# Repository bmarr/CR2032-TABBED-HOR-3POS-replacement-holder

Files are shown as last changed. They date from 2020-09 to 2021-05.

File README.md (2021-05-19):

# CR2032-TABBED-HOR-3POS-replacement-holder

Created in 2020 Braden Marr

This work is licensed under a Creative Commons Attribution-NonCommercial-ShareAlike 4.0 International Public License
https://creativecommons.org/licenses/by-nc-sa/4.0/

This is a replacement battery holder originally intended for the 3V battery inside the 1985-1987 Korg DW-8000 synthesizer keyboard, though it will likely work as a replacement in other PCB designs that used the 3 pin welded coin battery. This battery holder allows for easier swaps of common CR2032 3V lithium coin batteries. It requires a small paperclip cut into two lengths to act as the pins and pressure contacts of the battery holder.

The battery keeps the sound patches in memory, but without this backup current, the RAM loses the sound patches and the keyboard is generally unusable by itself, except as a MIDI keyboard.

The original factory-installed battery lasted about 10 years if the keyboard was rarely used. The original battery was directly soldered into the main PCB and requires skilled de-soldering and soldering to remove and replace.

The unique battery holder shape avoids interference with nearby components on the board that would otherwise prevent off-the-shelf battery holders from being installed in the original battery location; because this design uses the existing holes for the battery terminals, it avoids the need for other electrical modifications to relocate existing components elsewhere.

Skilled de-soldering and re-soldering is still required for this battery holder, but if done correctly it should only have to be done this once! Use clippers to remove the original battery from the circuit board, then use solder cleanup techniques to remove the pins left behind and remove any excess solder. A copper wick desoldering technique works well, and a 0.7mm paperclip can be used as a sort of pipe-cleaner to prepare the through holes (3 of them) for the paperclip-pins that will be used as the battery contacts.

Note: A paperclip with a wire diameter of about 0.7mm to 0.8mm is used with this battery holder as the battery contacts. The three battery holes on the PCB accept pins with about 0.8mm diameter. The paperclip is cut into two lengths which are then bent to fit within the channels of the battery holder to make the + and - contacts with the battery and act as the pins through the PCB. The + length of paperclip also acts as a retainer for the coin battery.

!!! Solder the paperclips to the PCB without the holder in place, as the plastic will melt !!!

DO NOT USE THE gcode FILE IN THIS REPOSITORY FOR PRINTING! It is specific to a custom printer design and is provided here only for reference.

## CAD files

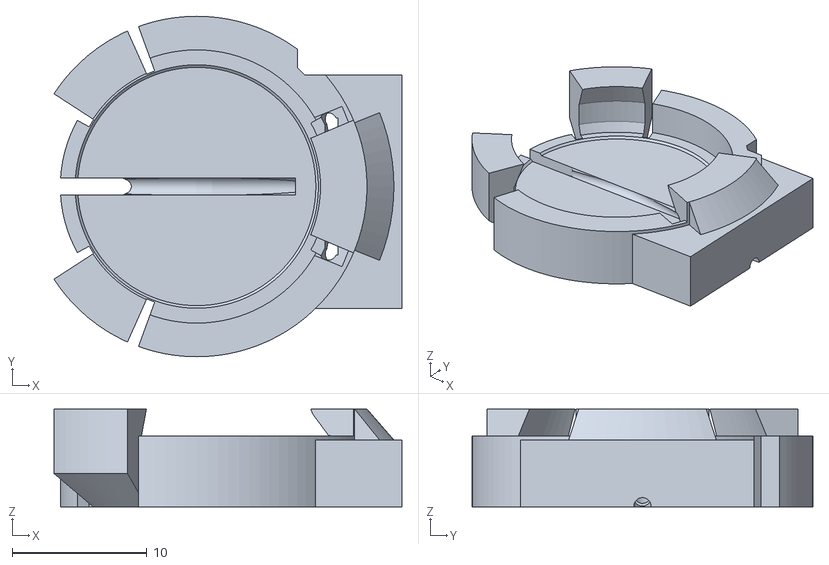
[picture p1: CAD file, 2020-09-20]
Korg-DW8000_CR2032-1GU_paperclip_battery_holder.stl
25.9 x 25.3 x 7.28

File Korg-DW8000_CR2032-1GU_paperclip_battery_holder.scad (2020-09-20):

// CR2032 battery socket for KORG DW8000
// Measurements based on datasheets for:
//  - Renesas CR2032-MFR-HR1/RH1 3-pin
//   industrial solder-in-place 225mAh Lithium battery,
//  - Panasonic CR2032-1GU 

$fn = 100;
d_coincell = 20; // 20 mm
d_coincell_tol = 0.3; // 0 to +0.3mm
d_coincell_neg = 17.7; // negative pad
h_coincell = 3.2; // 3.2 mm (2032)

d_min_hole_size = 0.7 + 0.25; // 0.7 from 1GU datasheet + IPC-2222 level A
d_min_annular_ring = 0.05; // 0.05mm
d_min_fab_allow = 0.6; // 0.6mm IPC-2222 level A
d_solder_pad = d_min_hole_size + d_min_annular_ring * 2 + d_min_fab_allow;
d_lead = 0.88; // 0.4 - 0.7mm for 1GU cell, paperclip = thicker? :)
d_hole_tol = 0.4; // FDM nozzle tolerance for small holes (for paperclips)

r_lead_pos_pin = 10.35;
y_lead_pos_pin1 = 10.15 / 2;
y_lead_pos_pin2 = -y_lead_pos_pin1;
y_lead_neg_pin = y_lead_pos_pin1 - 5.08;
x_lead_pos_pin1 = d_coincell / 2 + 0.35;
x_lead_pos_pin2 = x_lead_pos_pin1;
x_lead_neg_pin = x_lead_pos_pin1 - 16; // was 17.8, but then I measured the actual battery!
a_pos_pin = atan((y_lead_pos_pin1 - d_lead ) / (x_lead_pos_pin1 - d_lead / 2));
a_pos_pin_range = atan((y_lead_pos_pin1 + (d_lead / 2)) / (x_lead_pos_pin1 - d_lead / 2));
a_pos_pin_lean = -8;

h_holder_base = 1.2;
w_holder_walls = 2.5;
d_holder = d_coincell + d_coincell_tol + 2 * w_holder_walls;
a_holder_clip = 22; // angle of width of holder vertical flex tabs
h_holder_clip = 2; // height of clip overhang
w_holder_clip = 1; // extent of clip overhang
//w_holder_sweep = (sin(a_holder_clip) * ((d_coincell / 2) + d_coincell_tol + w_holder_walls)) / 2; // 
w_holder_sweep = w_holder_walls;
a_flex_relief_cut = 4; // 4 degrees for now, TODO: calculate

union() {
    difference() {
        union() {
            union() {
                difference() {
                    union() {
                        // battery enclosure
                        difference() {
                            translate([0, 0, 0])
                                cylinder(h = h_holder_base + d_lead + h_coincell, d1 = d_holder, d2 = d_holder);
                            translate([0, 0, h_holder_base + d_lead + 0.1])
                                coincell(h_coincell, d_coincell + d_coincell_tol, d_coincell_neg);
                        }
                        // upper retaining ring
                        translate([0, 0, h_holder_base + h_coincell + d_lead])
                            difference() {
                                difference() {
                                    translate([0, 0, 0])
                                        cylinder(h = h_holder_clip, d1 = d_holder, d2 = d_holder);
                                    translate([0, 0, -0.1])
                                        cylinder(h = h_holder_clip + 0.2, d1 = d_coincell + d_coincell_tol, d2 = d_coincell + d_coincell_tol - 2 * w_holder_clip);
                                }

                                // clip relief cuts
                                translate([0, 0, -0.01]) {
                                    // fingernail opening
                                    rotate(a = -180 - (a_holder_clip * 3) / 2, v = [0, 0, 1])
                                        rotate_extrude(angle = (a_holder_clip * 3), convexity = 10) {
                                                translate([d_coincell / 2 + (d_coincell_tol / 2) - w_holder_clip - 0.01, 0, 0])
                                                    square([w_holder_sweep + w_holder_clip + 0.02, h_holder_clip + 0.03]);
                                        }
                                    // leave tabs on both sides of fingernail opening
                                    rotate(a = a_pos_pin, v = [0, 0, 1])
                                        rotate_extrude(angle = 180 - a_pos_pin - 3 * a_holder_clip, convexity = 10) {
                                                translate([d_coincell / 2 + (d_coincell_tol / 2) - w_holder_clip - 0.01, 0, 0])
                                                    square([w_holder_sweep + w_holder_clip + 0.02, h_holder_clip + 0.03]);
                                        }
                                    rotate(a = -a_pos_pin, v = [0, 0, 1])
                                        rotate_extrude(angle = -a_pos_pin - 3 * a_holder_clip, convexity = 10) {
                                                translate([d_coincell / 2 + (d_coincell_tol / 2) - w_holder_clip - 0.01, 0, 0])
                                                    square([w_holder_sweep + w_holder_clip + 0.02, h_holder_clip + 0.03]);
                                        }
                                }
                            }
                        // flex tab base strengthening chamfer parallel to outside NEG edge of coincell
                        for (m = [0:1:1])
                            mirror(v = [0, m, 0])
                                translate([0, 0, h_holder_base + d_lead + (d_hole_tol / 2) - 0.01]) {
                                    rotate(a = -180 - a_holder_clip * 3, v = [0, 0, 1])
                                        rotate_extrude(angle = (a_holder_clip * 3) / 2, convexity = 10) {
                                                translate([d_coincell / 2 + (d_coincell_tol / 2) - (w_holder_clip / 2), 0, 0])
                                                    polygon(points = [[0, 0], [(w_holder_clip / 2), 0], [(w_holder_clip / 2) + 0.03, (w_holder_clip / 1)]]);
                                                    //square([w_holder_walls / 2 + 0.03, (h_holder_base + d_lead + d_hole_tol) / 2 + 0.03], center = false);
                                        }
                                }
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

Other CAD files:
tests/2020-09-20 DuetLEGO/Korg-DW8000_CR2032-1GU_paperclip_battery_holder.3mf

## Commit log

2020-09-17 Initial commit of CR2032 holder for 3 pin footprint (OpenSCAD)
    [Korg-DW8000_CR2032-1GU_paperclip_battery_holder.scad]
2020-09-17 Added breakout channels for POS pins to extend over top of battery and act as part of the holding mechanism.
    [Korg-DW8000_CR2032-1GU_paperclip_battery_holder.scad]
2020-09-18 Thickened holder walls by 0.5mm (2.5mm). Modified the channels for pins for easier bending. The printed test object did not function satisfactorily, however. May look at altering design for clip-on h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
    [Korg-DW8000_CR2032-1GU_paperclip_battery_holder.scad]
2020-09-18 Increased height of holder clip tabs. Cut back POS terminal area to allow closer contact with battery body. Shortened contact area for NEG terminal area. The test object had pretty good contact with 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
    [Korg-DW8000_CR2032-1GU_paperclip_battery_holder.scad]
2020-09-18 Changed positive terminal holes to a slot so that a wire loop can act as a battery clip. The negative terminal hole is now a slot. This allows the wires to be soldered onto the PCB first, then the ba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
    [Korg-DW8000_CR2032-1GU_paperclip_battery_holder.scad]
2020-09-19 Added positive lead locking tab to keep the lead from dropping down onto the negative lead.
    [Korg-DW8000_CR2032-1GU_paperclip_battery_holder.scad]
2020-09-20 Modified coin battery clip tabs to use longitudinal flex at base. Increased height of horizontal channel summit for NEG lead beneath battery to make better contact. Added successful PrusaSlicer 2.20 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
    [Korg-DW8000_CR2032-1GU_paperclip_battery_holder.scad, Korg-DW8000_CR2032-1GU_paperclip_battery_holder.stl]
2020-09-20 Added test files that did not seem to stage for commit previously.
    [Korg-DW8000_CR2032-1GU_paperclip_battery_holder.3mf]
2020-09-20 Changed NEG pin hole from 17.8 mm distance from POS pins to 16 mm to match actual 3-lead battery in Korg DM8000
    [Korg-DW8000_CR2032-1GU_paperclip_battery_holder.scad]
2020-09-20 Added body cutouts to accomodate Korg DM8000 C97 and R99 that collide with the holder body.
    [Korg-DW8000_CR2032-1GU_paperclip_battery_holder.scad]
2020-09-20 Added chamfer to keepout cutout for clearance with Korg DM8000 CPU board R99. Adjusted NEG lead horizontal chamber for better spring support.
    [Korg-DW8000_CR2032-1GU_paperclip_battery_holder.3mf, Korg-DW8000_CR2032-1GU_paperclip_battery_holder.scad, Korg-DW8000_CR2032-1GU_paperclip_battery_holder.stl]
2021-05-19 Create README.md
    This is essentially the description as it appears for the STL on thingiverse.com
2021-05-19 Update README.md
    Added warning about not using the gcode file found here. (Use the STL or regenerated it from OpenSCAD.
